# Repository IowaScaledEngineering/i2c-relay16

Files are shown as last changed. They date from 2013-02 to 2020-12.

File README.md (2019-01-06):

This is the software library, example applications, and hardware design files for the Iowa Scaled Engineering I2C-RELAY16 16-Channel Relay Board Driver

The board can be found at:
http://www.iascaled.com/store/I2C-RELAY16

Arduino control library documentation can be found on our wiki here:
https://www.iascaled.com/store/I2C-RELAY16-LIB

Like all public Iowa Scaled Engineering designs, the I2C-RELAY16 is both open hardware and open source software.  Please refer to the hardware and software license files in this repository for details.

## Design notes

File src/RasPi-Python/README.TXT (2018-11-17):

This is a simple class (relay16.py) and test driver (i2ctest-relay16.py) to
show how to control the I2C-RELAY16 via Python scripts on a Raspberry Pi or
similar embedded computer

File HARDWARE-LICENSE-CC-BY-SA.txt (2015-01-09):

The hardware design files for the Iowa Scaled Engineering I2C-RELAY16 are
open hardware, and licensed under the Creative Commons Attribution-Share
Alike license.

A copy can be found below, or from 
  http://creativecommons.org/licenses/by-sa/4.0/legalcode
-----------------------------------------------------------------------------

Creative Commons Attribution-ShareAlike 4.0 International Public License

By exercising the Licensed Rights (defined below), You accept and agree to
be bound by the terms and conditions of this Creative Commons
Attribution-ShareAlike 4.0 International Public License ("Public License").
To the extent this Public License may be interpreted as a contract, You are
granted the Licensed Rights in consideration of Your acceptance of these
terms and conditions, and the Licensor grants You such rights in
consideration of benefits the Licensor receives from making the Licensed
Material available under these terms and conditions.

Section 1 – Definitions.

    Adapted Material means material subject to Copyright and Similar Rights
that is derived from or based upon the Licensed Material and in which the
Licensed Material is translated, altered, arranged, transformed, or
otherwise modified in a manner requiring permission under the Copyright and
Similar Rights held by the Licensor. For purposes of this Public License,
where the Licensed Material is a musical work, performance, or sound
recording, Adapted Material is always produced where the Licensed Material
is synched in timed relation with a moving image.
    Adapter's License means the license You apply to Your Copyright and
Similar Rights in Your contributions to Adapted Material in accordance with
the terms and conditions of this Public License.
    BY-SA Compatible License means a license listed at
creativecommons.org/compatiblelicenses, approved by Creative Commons as
essentially the equivalent of this Public License.
    Copyright and Similar Rights means copyright and/or similar rights
closely related to copyright including, without limitation, performance,
broadcast, sound recording, and Sui Generis Database Rights, without regard
to how the rights are labeled or categorized. For purposes of this Public
License, the rights specified in Section 2(b)(1)-(2) are not Copyright and
Similar Rights.
    Effective Technological Measures means those measures that, in the
absence of proper authority, may not be circumvented under laws fulfilling
obligations under Article 11 of the WIPO Copyright Treaty adopted on
December 20, 1996, and/or similar international agreements.
    Exceptions and Limitations means fair use, fair dealing, and/or any
other exception or limitation to Copyright and Similar Rights that applies
to Your use of the Licensed Material.
    License Elements means the license attributes listed in the name of a
Creative Commons Public License. The License Elements of this Public License
are Attribution and ShareAlike.
    Licensed Material means the artistic or literary work, database, or
other material to which the Licensor applied this Public License.
    Licensed Rights means the rights granted to You subject to the terms and
conditions of this Public License, which are limited to all Copyright and
Similar Rights that apply to Your use of the Licensed Material and that the
Licensor has authority to license.
    Licensor means the individual(s) or entity(ies) granting rights under
this Public License.
    Share means to provide material to the public by any means or process
that requires permission under the Licensed Rights, such as reproduction,
public display, public performance, distribution, dissemination,
communication, or importation, and to make material available to the public
including in ways that members of the public may access the material from a
place and at a time individually chosen by them.
    Sui Generis Database Rights means rights other than copyright resulting
from Directive 96/9/EC of the European Parliament and of the Council of 11
March 1996 on the legal protection of databases, as amended and/or
succeeded, as well as other essentially equivalent rights anywhere in the
world.
    You means the individual or entity exercising the Licensed Rights under
this Public License. Your has a corresponding meaning.

Section 2 – Scope.

    License grant.
        Subject to the terms and conditions of this Public License, the
Licensor hereby grants You a worldwide, royalty-free, non-sublicensable,
non-exclusive, irrevocable license to exercise the Licensed Rights in the
Licensed Material to:
            reproduce and Share the Licensed Material, in whole or in part;
and
            produce, reproduce, and Share Adapted Material.
        Exceptions and Limitations. For the avoidance of doubt, where
Exceptions and Limitations apply to Your use, this Public License does not
apply, and You do not need to comply with its terms and conditions.
        Term. The term of this Public License is specified in Section 6(a).
        Media and formats; technical modifications allowed. The Licensor
authorizes You to exercise the Licensed Rights in all media and formats
whether now known or hereafter created, and to make technical modifications
necessary to do so. The Licensor waives and/or agrees not to assert any
right or authority to forbid You from making technical modifications
necessary to exercise the Licensed Rights, including technical modifications
necessary to circumvent Effective Technological Measures. For purposes of
this Public License, simply making modifications authorized by this Section
2(a)(4) never produces Adapted Material.
        Downstream recipients.
            Offer from the Licensor – Licensed Material. Every recipient of
the Licensed Material automatically receives an offer from the Licensor to
exercise the Licensed Rights under the terms and conditions of this Public
License.
            Additional offer from the Licensor – Adapted Material. Every
recipient of Adapted Material from You automatically receives an offer from
the Licensor to exercise the Licensed Rights in the Adapted Material under
the conditions of the Adapter’s License You apply.
            No downstream restrictions. You may not offer or impose any
additional or different terms or conditions on, or apply any Effective
Technological Measures to, the Licensed Material if doing so restricts
exercise of the Licensed Rights by any recipient of the Licensed Material.
        No endorsement. Nothing in this Public License constitutes or may be
construed as permission to assert or imply that You are, or that Your use of
the Licensed Material is, connected with, or sponsored, endorsed, or granted
official status by, the Licensor or others designated to receive attribution
as provided in Section 3(a)(1)(A)(i).

    Other rights.
        Moral rights, such as the right of integrity, are not licensed under
this Public License, nor are publicity, privacy, and/or other similar
personality rights; however, to the extent possible, the Licensor waives
and/or agrees not to assert any such rights held by the Licensor to the
limited extent necessary to allow You to exercise the Licensed Rights, but
not otherwise.
        Patent and trademark rights are not licensed under this Public
License.
        To the extent possible, the Licensor waives any right to collect
royalties from You for the exercise of the Licensed Rights, whether directly
or through a collecting society under any voluntary or waivable statutory or
compulsory licensing scheme. In all other cases the Licensor expressly
reserves any right to collect such royalties.

Section 3 – License Conditions.

Your exercise of the Licensed Rights is expressly made subject to the
following conditions.

    Attribution.

        If You Share the Licensed Material (including in modified form), You
must:
            retain the following if it is supplied by the Licensor with the
Licensed Material:
                identification of the creator(s) of the Licensed Material
and any others designated to receive attribution, in any reasonable manner
requested by the Licensor (including by pseudonym if designated);
                a copyright notice;
                a notice that refers to this Public License;
                a notice that refers to the disclaimer of warranties;
                a URI or hyperlink to the Licensed Material to the extent
                reasonably practicable;
            indicate if You modified the Licensed Material and retain an
indication of any previous modifications; and
            indicate the Licensed Material is licensed under this Public
License, and include the text of, or the URI or hyperlink to, this Public
License.
        You may satisfy the conditions in Section 3(a)(1) in any reasonable
manner based on the medium, means, and context in which You Share the
Licensed Material. For example, it may be reasonable to satisfy the
conditions by providing a URI or hyperlink to a resource that includes the
required information.
        If requested by the Licensor, You must remove any of the information
required by Section 3(a)(1)(A) to the extent reasonably practicable.
    ShareAlike.

    In addition to the conditions in Section 3(a), if You Share Adapted
Material You produce, the following conditions also apply.
        The Adapter’s License You apply must be a Creative Commons license
with the same License Elements, this version or later, or a BY-SA Compatible
License.
        You must include the text of, or the URI or hyperlink to, the
Adapter's License You apply. You may satisfy this condition in any
reasonable manner based on the medium, means, and context in which You Share
Adapted Material.
        You may not offer or impose any additional or different terms or
conditions on, or apply any Effective Technological Measures to, Adapted
Material that restrict exercise of the rights granted under the Adapter's
License You apply.

Section 4 – Sui Generis Database Rights.

Where the Licensed Rights include Sui Generis Database Rights that apply to
Your use of the Licensed Material:

    for the avoidance of doubt, Section 2(a)(1) grants You the right to
extract, reuse, reproduce, and Share all or a substantial portion of the
contents of the database;
    if You include all or a substantial portion of the database contents in
a database in which You have Sui Generis Database Rights, then the database
in which You have Sui Generis Database Rights (but not its individual
contents) is Adapted Material, including for purposes of Section 3(b); and
    You must comply with the conditions in Section 3(a) if You Share all or
a substantial portion of the contents of the database.

For the avoidance of doubt, this Section 4 supplements and does not replace
Your obligations under this Public License where the Licensed Rights include
other Copyright and Similar Rights.

Section 5 – Disclaimer of Warranties and Limitation of Liability.

    Unless otherwise separately undertaken by the Licensor, to the extent
possible, the Licensor offers the Licensed Material as-is and as-available,
and makes no representations or warranties of any kind concerning the
Licensed Material, whether express, implied, statutory, or other. This
includes, without limitation, warranties of title, merchantability, fitness
for a particular purpose, non-infringement, absence of latent or other
defects, accuracy, or the presence or absence of errors, whether or not
known or discoverable. Where disclaimers of warranties are not allowed in
full or in part, this disclaimer may not apply to You.
    To the extent possible, in no event will the Licensor be liable to You
on any legal theory (including, without limitation, negligence) or otherwise
for any direct, special, indirect, incidental, consequential, punitive,
exemplary, or other losses, costs, expenses, or damages arising out of this
Public License or use of the Licensed Material, even if the Licensor has
been advised of the possibility of such losses, costs, expenses, or damages.
Where a limitation of liability is not allowed in full or in part, this
limitation may not apply to You.

    The disclaimer of warranties and limitation of liability provided above
shall be interpreted in a manner that, to the extent possible, most closely
approximates an absolute disclaimer and waiver of all liability.

Section 6 – Term and Termination.

    This Public License applies for the term of the Copyright and Similar
Rights licensed here. However, if You fail to comply with this Public
License, then Your rights under this Public License terminate automatically.

    Where Your right to use the Licensed Material has terminated under
Section 6(a), it reinstates:
        automatically as of the date the violation is cured, provided it is
cured within 30 days of Your discovery of the violation; or
        upon express reinstatement by the Licensor.
    For the avoidance of doubt, this Section 6(b) does not affect any right
the Licensor may have to seek remedies for Your violations of this Public
License.
    For the avoidance of doubt, the Licensor may also offer the Licensed
Material under separate terms or conditions or stop distributing the
Licensed Material at any time; however, doing so will not terminate this
Public License.
    Sections 1, 5, 6, 7, and 8 survive termination of this Public License.

Section 7 – Other Terms and Conditions.

    The Licensor shall not be bound by any additional or different terms or
conditions communicated by You unless expressly agreed.
    Any arrangements, understandings, or agreements regarding the Licensed
Material not stated herein are separate from and independent of the terms
and conditions of this Public License.

Section 8 – Interpretation.

    For the avoidance of doubt, this Public License does not, and shall not
be interpreted to, reduce, limit, restrict, or impose conditions on any use
of the Licensed Material that could lawfully be made without permission
under this Public License.
    To the extent possible, if any provision of this Public License is
deemed unenforceable, it shall be automatically reformed to the minimum
extent necessary to make it enforceable. If the provision cannot be
reformed, it shall be severed from this Public License without affecting the
enforceability of the remaining terms and conditions.
    No term or condition of this Public License will be waived and no
failure to comply consented to unless expressly agreed to by the Licensor.
    Nothing in this Public License constitutes or may be interpreted as a
limitation upon, or waiver of, any privileges and immunities that apply to
the Licensor or You, including from the legal processes of any jurisdiction
or authority.

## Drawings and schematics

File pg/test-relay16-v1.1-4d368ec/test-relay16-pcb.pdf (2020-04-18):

# test-relay16.pcb

# 1. Table of Contents (This Page) Created on Wed Mar 4 20:13:11 2020

# 2. top 3. bottom 4. outline 5. plated-drill 6. componentmask 7. soldermask 8. topsilk 9. bottomsilk 10. toppaste 11. topassembly 12. bottomassembly 13. fab

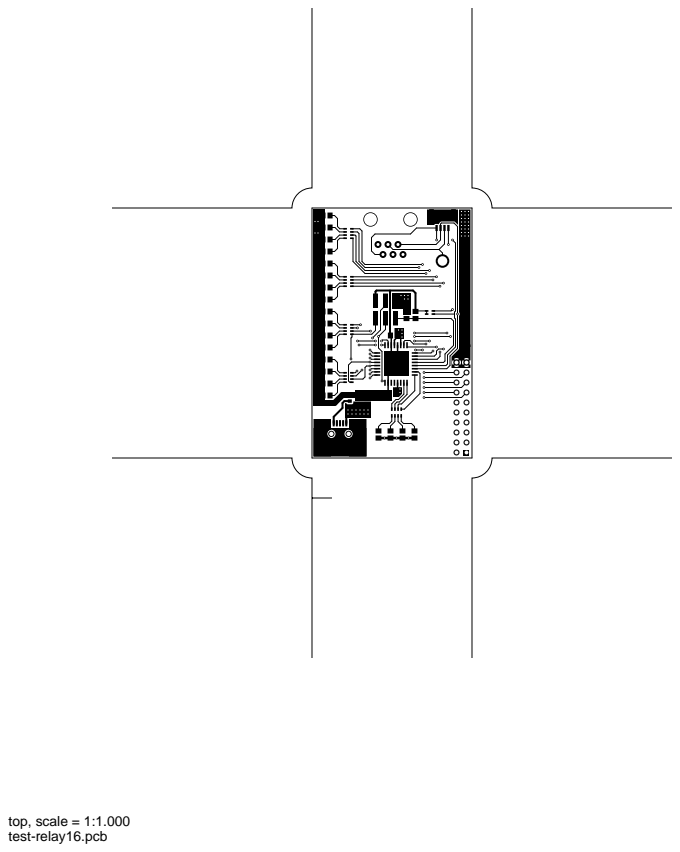
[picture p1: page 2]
top, scale = 1:1.000

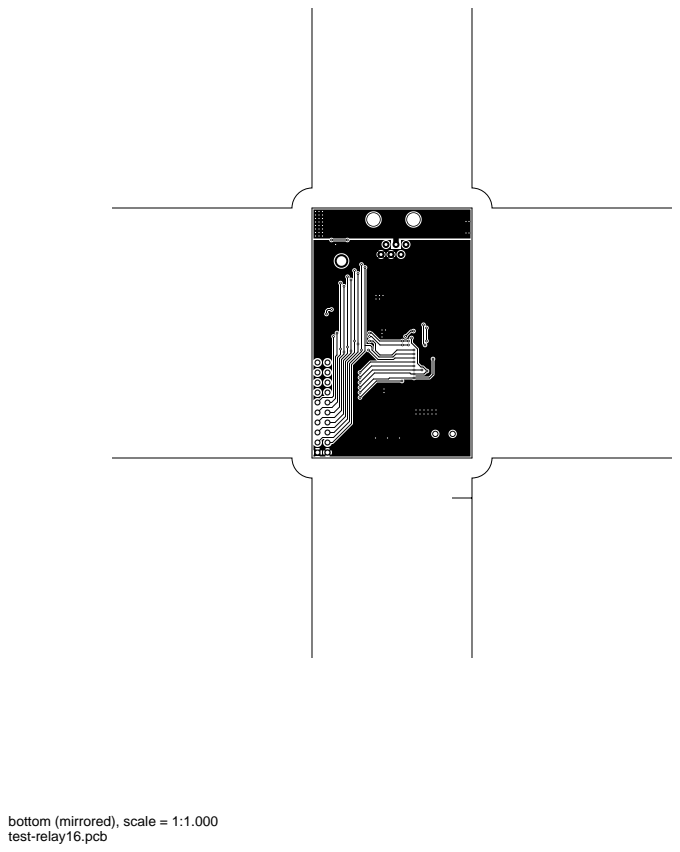
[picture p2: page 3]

bottom (mirrored), scale = 1:1.000

outline, scale = 1:1.000

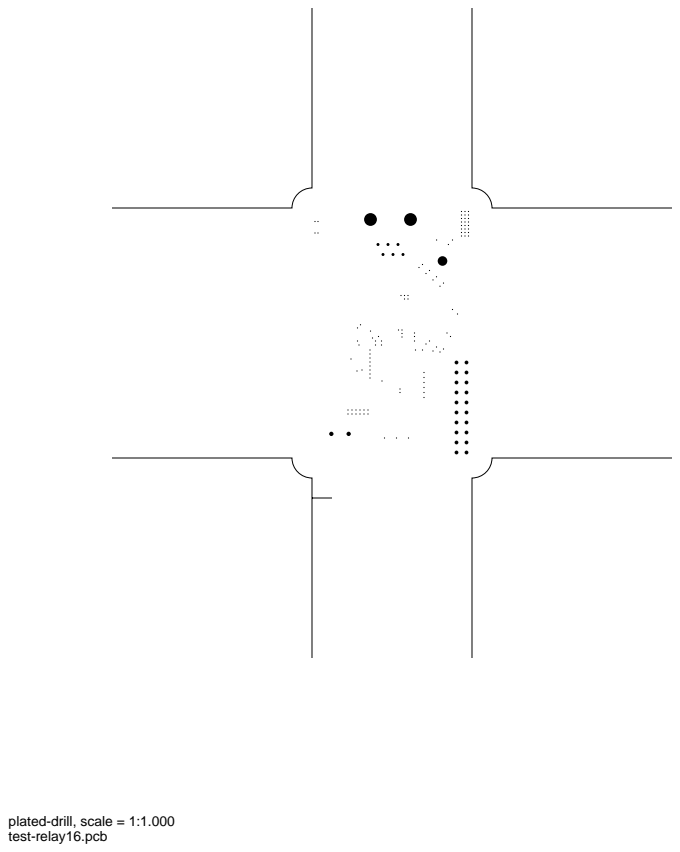
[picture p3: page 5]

plated-drill, scale = 1:1.000

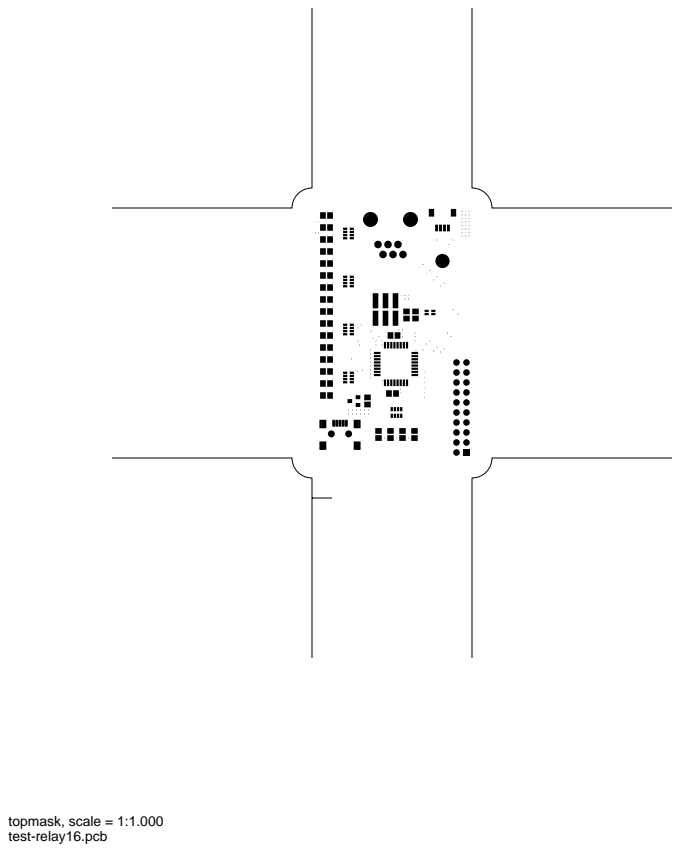
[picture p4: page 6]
topmask, scale = 1:1.000

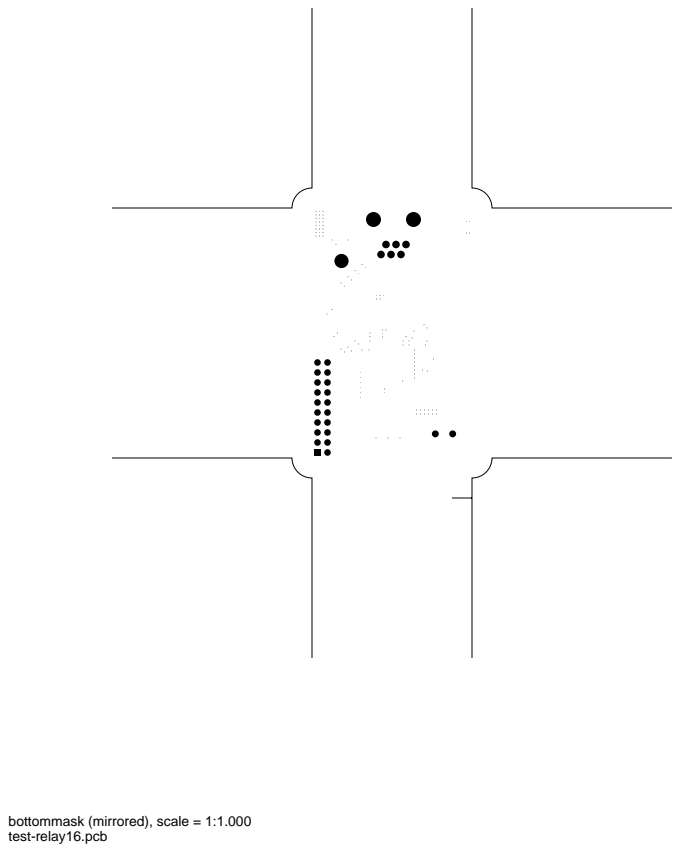
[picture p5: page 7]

bottommask (mirrored), scale = 1:1.000

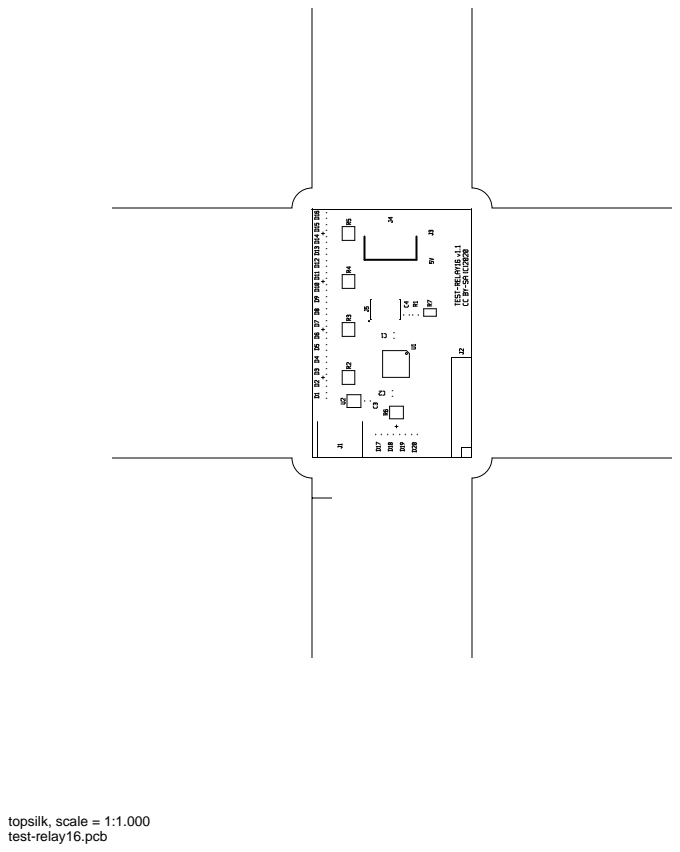
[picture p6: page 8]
topsilk, scale = 1:1.000

bottomsilk (mirrored), scale = 1:1.000

toppaste, scale = 1:1.000

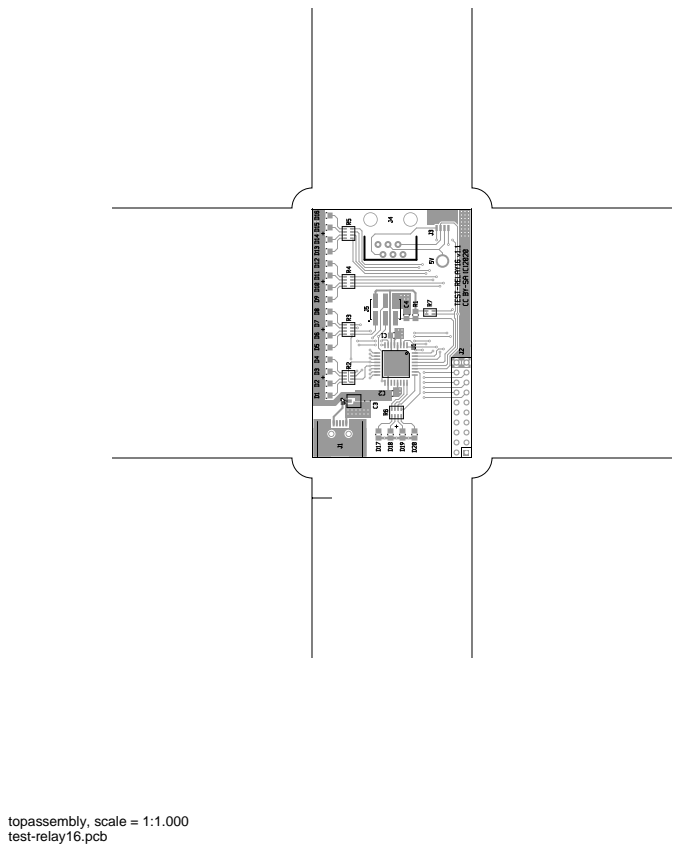
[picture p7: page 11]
topassembly, scale = 1:1.000

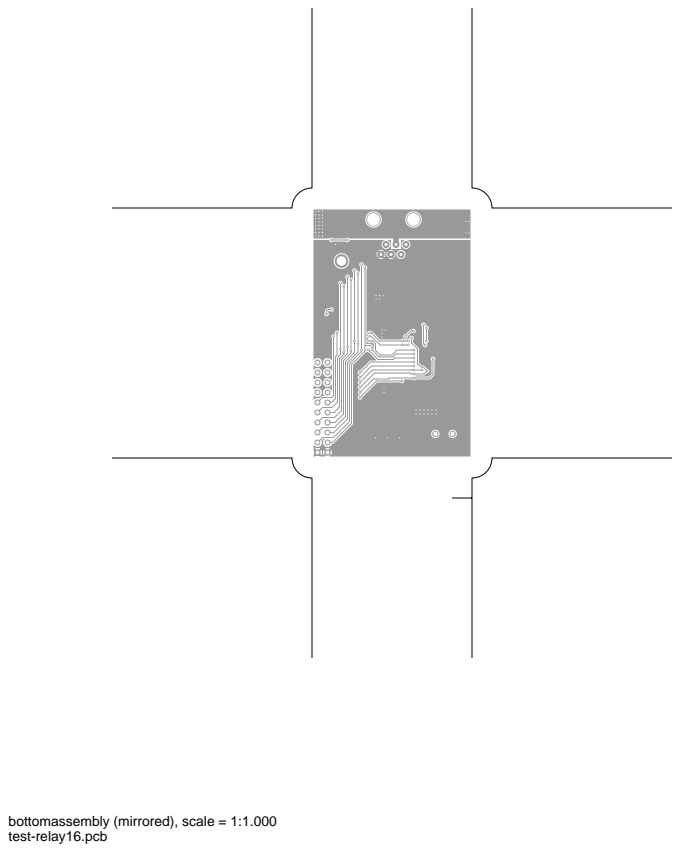
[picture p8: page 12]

bottomassembly (mirrored), scale = 1:1.000

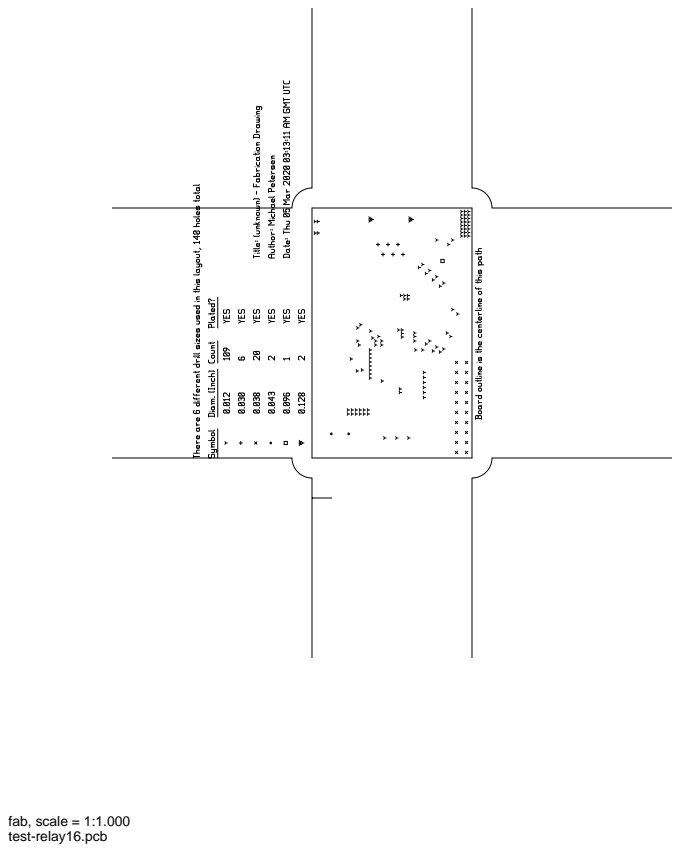
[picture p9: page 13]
fab, scale = 1:1.000

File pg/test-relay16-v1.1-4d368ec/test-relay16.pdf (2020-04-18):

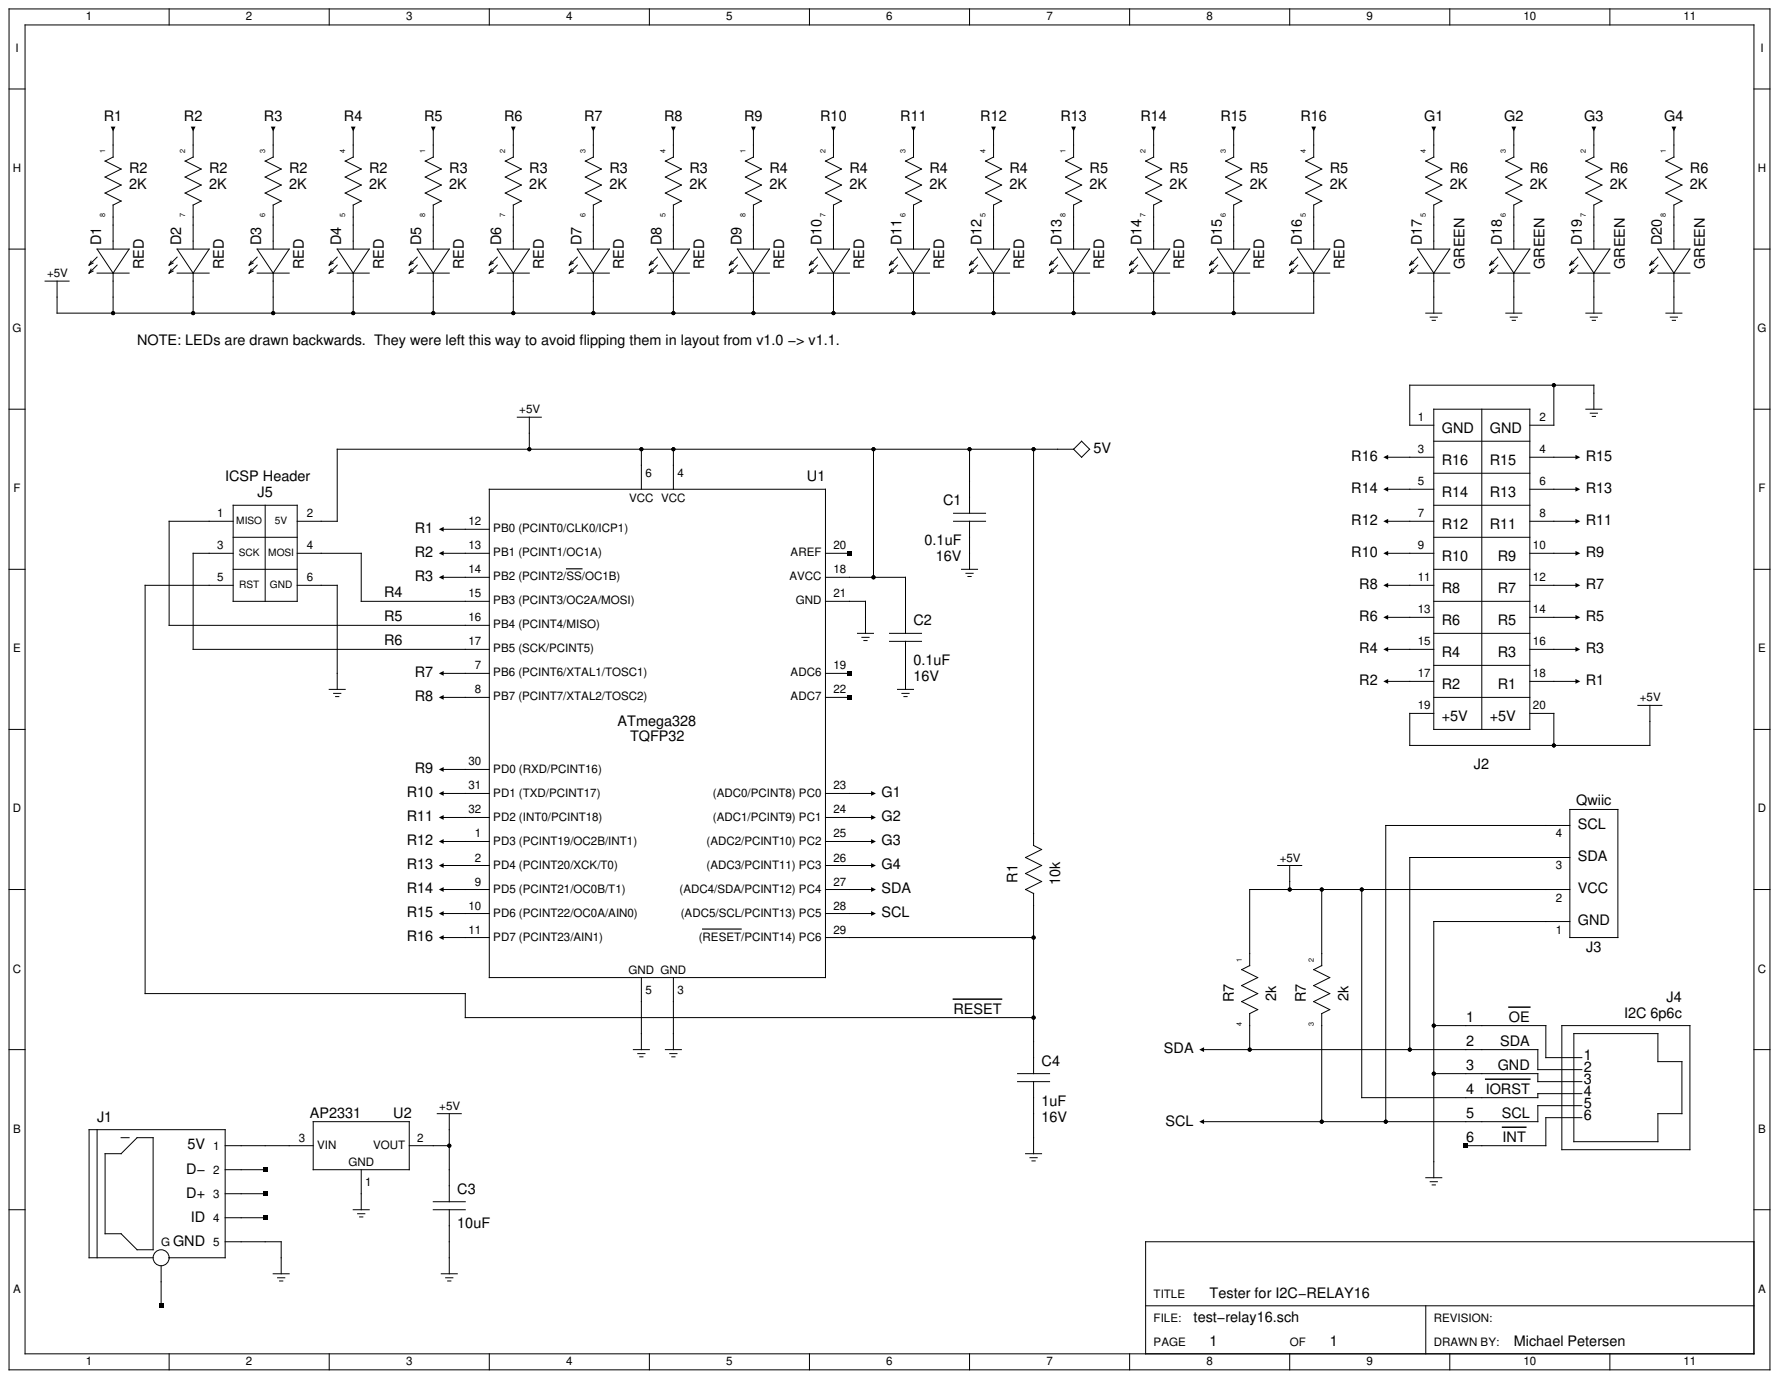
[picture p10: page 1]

NOTE: LEDs are drawn backwards. They were left this way to avoid flipping them in layout from v1.0 −> v1.1.

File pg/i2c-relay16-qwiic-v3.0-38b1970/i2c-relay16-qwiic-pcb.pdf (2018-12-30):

# i2c-relay16-qwiic.pcb

# 1. Table of Contents (This Page) Created on Sun Dec 30 12:12:51 2018

# 2. component 3. solder 4. outline 5. plated-drill 6. componentmask 7. soldermask 8. topsilk 9. bottomsilk 10. toppaste 11. topassembly 12. bottomassembly 13. fab

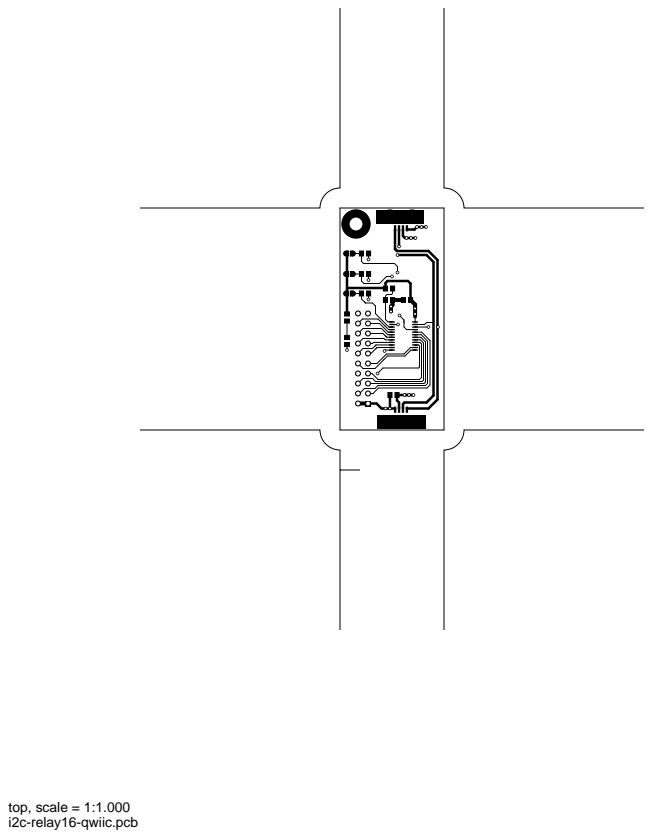
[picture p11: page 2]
top, scale = 1:1.000

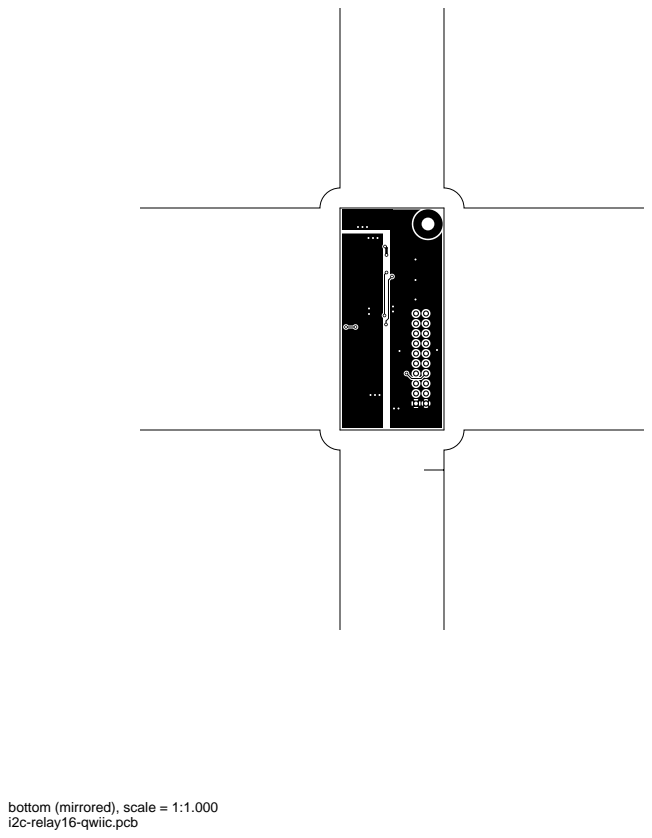
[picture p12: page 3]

bottom (mirrored), scale = 1:1.000

outline, scale = 1:1.000


plated-drill, scale = 1:1.000


topmask, scale = 1:1.000


bottommask (mirrored), scale = 1:1.000

topsilk, scale = 1:1.000

bottomsilk (mirrored), scale = 1:1.000

toppaste, scale = 1:1.000

topassembly, scale = 1:1.000


bottomassembly (mirrored), scale = 1:1.000

fab, scale = 1:1.000

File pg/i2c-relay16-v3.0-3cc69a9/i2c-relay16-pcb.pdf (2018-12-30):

# i2c-relay16.pcb

# 1. Table of Contents (This Page) Created on Thu Nov 29 15:04:31 2018

# 2. component 3. solder 4. outline 5. plated-drill 6. componentmask 7. soldermask 8. topsilk 9. bottomsilk 10. toppaste 11. topassembly 12. bottomassembly 13. fab

top, scale = 1:1.000


bottom (mirrored), scale = 1:1.000

outline, scale = 1:1.000


plated-drill, scale = 1:1.000

topmask, scale = 1:1.000


bottommask (mirrored), scale = 1:1.000

topsilk, scale = 1:1.000

bottomsilk (mirrored), scale = 1:1.000

toppaste, scale = 1:1.000

topassembly, scale = 1:1.000


bottomassembly (mirrored), scale = 1:1.000

fab, scale = 1:1.000

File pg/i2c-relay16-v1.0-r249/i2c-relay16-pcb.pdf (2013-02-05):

# i2c-relay16.pcb

# 1. Table of Contents (This Page) Created on Mon Feb 4 20:55:55 2013

# 2. component 3. solder 4. plated-drill 5. componentmask 6. soldermask 7. topsilk 8. bottomsilk 9. toppaste 10. topassembly 11. bottomassembly 12. fab

top, scale = 1:1.000


bottom (mirrored), scale = 1:1.000


plated-drill, scale = 1:1.000

topmask, scale = 1:1.000


bottommask (mirrored), scale = 1:1.000

topsilk, scale = 1:1.000

bottomsilk (mirrored), scale = 1:1.000

toppaste, scale = 1:1.000

topassembly, scale = 1:1.000


bottomassembly (mirrored), scale = 1:1.000

fab, scale = 1:1.000

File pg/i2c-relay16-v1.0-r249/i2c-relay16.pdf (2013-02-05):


2 | SDA 2

GND


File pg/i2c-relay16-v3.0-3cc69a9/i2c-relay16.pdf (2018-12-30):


*Jack as viewed from front

5 5 SCL

/INT 6

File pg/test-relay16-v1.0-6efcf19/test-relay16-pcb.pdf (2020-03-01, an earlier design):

# test-relay16.pcb

# 1. Table of Contents (This Page) Created on Sun Feb 16 21:19:00 2020

# 2. top 3. bottom 4. outline 5. plated-drill 6. componentmask 7. soldermask 8. topsilk 9. bottomsilk 10. toppaste 11. topassembly 12. bottomassembly 13. fab

top, scale = 1:1.000


bottom (mirrored), scale = 1:1.000

outline, scale = 1:1.000


plated-drill, scale = 1:1.000

topmask, scale = 1:1.000


bottommask (mirrored), scale = 1:1.000

topsilk, scale = 1:1.000

bottomsilk (mirrored), scale = 1:1.000

toppaste, scale = 1:1.000

topassembly, scale = 1:1.000


bottomassembly (mirrored), scale = 1:1.000

fab, scale = 1:1.000

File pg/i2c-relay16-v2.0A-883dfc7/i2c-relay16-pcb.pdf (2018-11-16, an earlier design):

# i2c-relay16.pcb

# 1. Table of Contents (This Page) Created on Thu Aug 30 13:24:04 2018

# 2. component 3. solder 4. outline 5. plated-drill 6. componentmask 7. soldermask 8. topsilk 9. bottomsilk 10. toppaste 11. topassembly 12. bottomassembly 13. fab

top, scale = 1:1.000


bottom (mirrored), scale = 1:1.000

outline, scale = 1:1.000


plated-drill, scale = 1:1.000

topmask, scale = 1:1.000


bottommask (mirrored), scale = 1:1.000

topsilk, scale = 1:1.000

bottomsilk (mirrored), scale = 1:1.000

toppaste, scale = 1:1.000

topassembly, scale = 1:1.000


bottomassembly (mirrored), scale = 1:1.000

fab, scale = 1:1.000


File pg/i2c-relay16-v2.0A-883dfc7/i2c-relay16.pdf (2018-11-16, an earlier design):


*Jack as viewed from front

5 5 SCL

/INT 6

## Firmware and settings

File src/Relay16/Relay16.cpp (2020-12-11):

/*************************************************************************
Title:    Iowa Scaled Engineering I2C-RELAY16 Driver Library
Authors:  Nathan D. Holmes <maverick@drgw.net>
File:     $Id: $
License:  GNU General Public License v3

LICENSE:
    Copyright (C) 2014 Nathan D. Holmes & Michael D. Petersen

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
    For more information about the Iowa Scaled Engineering I2C-RELAY16, see:
    http://www.iascaled.com/store/I2C-RELAY16

*************************************************************************/

#include <stdlib.h>
#include <string.h>
#include "Arduino.h"
#include "Wire.h"
#include "Relay16.h"

Relay16::Relay16()
{
	this->addr = 0;
	this->relayBits = 0; // All relays off
	this->dioReset = -1; // Unknown digital I/O for the reset line
}

void Relay16::refresh()
{
   Wire.beginTransmission(this->addr);
   Wire.write(~(this->relayBits & 0xFF));
   Wire.write(~((this->relayBits >> 8) & 0xFF));
   Wire.endTransmission();
}


void Relay16::allOff()
{
	this->relayBits = 0;
	refresh();
}

void Relay16::allOn()
{
	this->relayBits = 0xFFFF;
	refresh();
}

void Relay16::relayOn(byte relayNum)
{
	if (relayNum < 1 || relayNum > 16)
		return;
	this->relayBits |= 1<<(relayNum-1);
	refresh();
}

void Relay16::relayOff(byte relayNum)
{
	if (relayNum < 1 || relayNum > 16)
		return;
	this->relayBits &= ~(1<<(relayNum-1));
	refresh();
}


void Relay16::begin(boolean j5, boolean j6, boolean j7, char dioResetPin)
{
	uint8_t addrBitmap = (j5?0x01:0x00) | (j6?0x02:0x00) | (j7?0x04:0x00);
	this->addr = 0x20 | (addrBitmap);
	
	// If there's a DIO pin assigned to reset, use it to do a hardware reset on initialization
	if (-1 != dioResetPin)
	{
		pinMode(dioResetPin, OUTPUT);
		digitalWrite(dioResetPin, LOW);
		delayMicroseconds(100);
		digitalWrite(dioResetPin, HIGH);
	}
	
	this->allOff();
}

void Relay16::begin(uint8_t address, char dioResetPin)
{
	this->addr = address;
	
	// If there's a DIO pin assigned to reset, use it to do a hardware reset on initialization
	if (-1 != dioResetPin)
	{
		pinMode(dioResetPin, OUTPUT);
		digitalWrite(dioResetPin, LOW);
		delayMicroseconds(100);
		digitalWrite(dioResetPin, HIGH);
	}
	
	this->allOff();
}

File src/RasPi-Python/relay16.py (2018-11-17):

import smbus

class relay16:
  bus = 0
  address = 0x00
  relayState = 0x0000
   
  def __init__(self, bus, address):
    self.bus = bus
    self.address = address
    self.relayState = 0x0000
    self.sendRelayStates()

  def clearAllRelays(self):
    self.relayState = 0x0000
    self.sendRelayStates()
    
  def setRelay(self, relayNum):
    if relayNum < 1 or relayNum > 16:
      return
    self.relayState |= 1<<(relayNum-1)
    self.sendRelayStates()
  
  def clearRelay(self, relayNum):
    if relayNum < 1 or relayNum > 16:
      return
    self.relayState &= ~(1<<(relayNum-1))
    self.sendRelayStates()  

  def sendRelayStates(self):
    self.bus.write_byte_data(self.address, 0xFF & ~(self.relayState), 0xFF & (~(0x00FF & (self.relayState>>8))));

                 
   

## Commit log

2013-01-20 I2C driver for 16 channel relay board
    [i2c-relay16.sch]
2013-01-23 Fixed soldermask on TSSOP24 Added ground plane fill Fixed pin centering on traces entering TSSOP24
2013-02-03 Add PG files.
    [i2c-relay16.bottom.gbr, i2c-relay16.bottommask.gbr, i2c-relay16.fab.gbr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]
2013-02-05 New PG.
    [i2c-relay16.bottom.gbr, i2c-relay16.bottommask.gbr, i2c-relay16.bottompaste.gbr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]
2013-10-29 Test code for relay16
2014-07-08 Create Arduino library and example sketch for i2c-relay16
2014-11-14 Clarify jack layout
    [i2c-relay16.sch]
2015-02-02 Tapeout with outline layer, v1.1.
    [i2c-relay16.bottom.gbr, i2c-relay16.bottommask.gbr, i2c-relay16.bottompaste.gbr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]
2016-02-04 Update project to use github i2c library for test program
2016-05-08 v1.2 Changed to offset hole 3pin jumpers. Move mounting hole inboard 5mils,5mils to clear DRC error with outline layer.
    [i2c-relay16.sch]
2016-05-10 i2c-relay16 pg 1.2
    [i2c-relay16.bottom.gbr, i2c-relay16.bottommask.gbr, i2c-relay16.bottompaste.gbr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]
2016-05-10 Change D1 to 0805, add polarity indicator
    [i2c-relay16.sch]
2016-05-10 Undo pg 1.2
    [i2c-relay16.bottom.gbr, i2c-relay16.bottommask.gbr, i2c-relay16.bottompaste.gbr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]
2016-05-10 Add new pg 1.2 with fixed diode
    [i2c-relay16.bottom.gbr, i2c-relay16.bottommask.gbr, i2c-relay16.bottompaste.gbr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]
2017-02-21 v2 prototype
    [i2c-relay16.sch]
2017-02-22 Added C1. Improved GND plane on top.
    [i2c-relay16.sch]
2017-02-22 Prep for J8/J9
    [i2c-relay16.sch]
2017-02-22 Wired J8/J9
    [i2c-relay16.sch]
2017-02-24 Added R3, optional reset pull-up. Cleaned up silk around jumpers. Cleaned up traces/GND plane.
    [i2c-relay16.sch]
2017-03-04 Sent to fab 3/3/2017
    [i2c-relay16.bottom.gbr, i2c-relay16.bottommask.gbr, i2c-relay16.bottompaste.gbr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]
2017-04-14 Add a Raspberry Pi example for controlling the relay16 written in Python
2018-08-30 Reduced U1 solder paste
2018-11-16 Files with reduced solder paste
    [i2c-relay16.bottom.gbr, i2c-relay16.bottommask.gbr, i2c-relay16.bottompaste.gbr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]
2018-11-17 v3 design
    [i2c-relay16.sch]
2018-12-30 Add qwiic version of i2c-relay16
    [i2c-relay16-qwiic.sch]
2018-12-30 Sent to Seeed
    [i2c-relay16-qwiic.bottom.gbr, i2c-relay16-qwiic.bottommask.gbr, i2c-relay16-qwiic.bottompaste.gbr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]
2020-02-15 Initial test board design
    [test-relay16.sch]
2020-02-17 Improvements after review
    [test-relay16.sch]
2020-03-01 Sent to fab
    [test-relay16.bottom.gbr, test-relay16.bottommask.gbr, test-relay16.bottompaste.gbr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]
2020-03-01 Flipped LEDs since the 9671 can sink, but not source (much). v1.1
    [test-relay16.sch]
2020-03-05 Added 5V terminal for driving address lines
    [test-relay16.sch]
2020-04-18 Fab files
    [test-relay16.bottom.gbr, test-relay16.bottommask.gbr, test-relay16.bottompaste.gbr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]
2020-12-11 Add prototype to Arduino begin() function to allow setting of address directly
